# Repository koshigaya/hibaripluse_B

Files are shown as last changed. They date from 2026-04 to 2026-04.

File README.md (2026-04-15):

# hibaripluse_B
plethysmograph     

HibariPulse Basic is  a medical instrument, plethysmograph developed by Future Wave,Inc. in Tokyo, Japan.
We show source code, schematics, PCB layout and other information about HibariPulse Basic.

Hibari Pulse Basic is composed of sensor and PC apprication software. The sensor is connected to Windows PC by USB cable. PC apprication software is distributed in CD-R.

DD151207 is the folder of device driver for USB. Hibari Pulse Basic uses the device driver of FTDI,Inc. The user should install both PC apprication software and the device driver.

SK121105_delay10 is the folder of firmware.

pats_list111004.xls is BOM. The PCB has socket, but no MPU. MPU is ATMEGA328p-PU by Microchip Technology,Inc. 
So, first, we burn firmware on ROM in MPU. Second, we insert MPU on the socket.

apprication software :  Visual studio 2010(C#)  firmware :Arduino IDE  schematics:CADLUS Design by Nisoul, Inc.  PCB laout:CADLUS X by Nisoul. Inc.  CASE: JW-CAD(customized product byTAKACHI Co,.LTD)

***********************************
https://youtu.be/cTy66kJvDls?si=9v41cSytfnO6r9-v     another version (with OLED) https://youtu.be/LcAzEBJ3FTY?si=bp07WSiirY0aO0Qf

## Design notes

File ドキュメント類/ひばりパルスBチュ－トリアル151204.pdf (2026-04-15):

## ひばりパルス ベーシック

## 取扱説明書チュートリアル編

この取扱説明書はひばりパルス ベーシ
ックをはじめて使う方のための簡易版です。
詳しい情報は取扱説明書リファレンス編に
掲載されています。
取扱説明書リファレンス編は PDF デー
タで CD-R 内に入っています。または以下
の弊社サイトからダウンロードできます。

(http://www.bcchecker.com/docdown)

1.入っているもの
本体／CD-R／USB ケーブル／マウスパッ
ド／添付文書／取扱説明書チュートリアル
編(本書)

2.対応する PC について
本製品は Windows *PC と接続して使用
することを前提にしています。単独では作
動しませんのでご注意ください(Windows
は Microsoft 社の登録商標です)。
以下の PC で動作します。
①OS(いずれも 64 ビット版)：

Windows7, Windows8, Windows8.1,

Windows10
②CPU：Corei3 以上を推奨

3.注意事項
・ペースメーカーを装着している方は使用
しないでください。
・電源投入時(緑色 LED 点灯時)はセンサ部
から常時赤外線が発光していますので、
センサ部に眼を近づけないで下さい。

・電源投入時(緑色 LED 点灯時)は怪我や炎
症のある体の部位をセンサ部に接触させ
ないで下さい。
・測定中、センサ部に当てた指先に強い痛
みを感じたり、火傷したりしたときは、
ただちに測定を中止し、必要に応じて医
師の診断を受けて下さい。
・測定結果の自己診断、治療は危険ですの
で医師の指導に従って下さい。
・故障した場合は自分で修理、分解せず、
弊社までご連絡下さい。
・本製品に水をかけると故障する場合があ
ります。

4.インストール方法
最初にデバイスドライバをインストール
し、次にアプリケーションソフトをインス
トールします。デバイスドライバは CD-R
内のフォルダ「DD151207」の中に入って
います。
① PC の光学ドライバに付属の CD-R を挿
入します。
② 本製品本体と PC を USB ケーブルで接
続します。
③ デバイスドライバをインストールしま
す。インストールが完了すると正常にイ
ンストールされた旨のメッセージが出
力されます。
④ 通常、自動的にデバイスドライバのイン
ストールが始まりますので、画面の指示
に従ってください。途中、ディスクを挿

入する旨のメッセージが出力されたら、
①の通り挿入したことを確認して「次へ」
をクリックしてください。
うまく作動しない場合は手動のインス
トールに切り替えてください(詳細は取
扱説明書リファレンス編を参照)。
⑤ お使いの PC や環境によっては、手動で
インストールしなくてはならない場合
があります。その場合、デバイスドライ
バの参照先に CD-R 内のフォルダ
「DD151207」を指定します(詳細は取
扱説明書リファレンス編を参照)。
⑥ デバイスドライバのインストールが終
了したら、次にアプリケーションソフト
をインストールします。

⑦ まず CD-R 内の「Setup151202」をダ ブルクリックし、画面の指示に従います。
⑧ アイコンがデスクトップに表示された
ら、インストール作業はすべて完了です。

5.アプリケーションソフトの操作法
① ひばりパルス ベーシック本体と PC
を USB ケーブルで接続します。
② デスクトップ上のアイコンをダブルク
リックし、アプリケーションソフトを立
ち上げます。
③ 画面の空欄に被測定者の年齢を入力し
た後、「測定画面」をクリックし、「測定
画面」を立ち上げます。
④ 血管年齢を表示する場合はメニューバ
ーの機能(F)＞血管年齢の表示／非表示
(V)をクリックします。
⑤ 被測定者の指先を本体センサ部に載せ
ます。
⑥ 「測定」ボタンをクリックし、測定を開
始します。

⑦ 測定中、被測定者は体を動かさず、静か
にしています。
⑧ 測定が終了するとメッセージが出力さ
れます。測定結果の見方は図 1 を参照
してください。
⑨ 結果を印字する場合は「印刷」ボタンを
クリックしてください。
データを保存する場合はメニューバー
のファイル(F)＞データ書き込み(W)を
クリックしてください。保存したデータ
を見るときは、「測定画面」を閉じ、最
初の画面から「ビューワ」をクリックし
ます。「ビューワ」画面が立ち上がり、
保存データを見ることができます。
⑩ 22 波形分類で測定するときは機能(F)
＞22 波形分類／7 波形分類(Ｗ)をクリ
ックします。
後は 7 波形分類と操作法は同じです。
測定結果の見方は図 2 を参照してくだ
さい。

6.3 波形表示の操作法
最初の画面から「3 波形表示」をクリッ
クすると、「3 波形表示」画面が立ち上がり
ます。「3 波形表示」画面では加速度脈波の
他、容積脈波や速度脈波をモニタ表示でき
ます。

7.貯蔵方法
次のようなところに保管して下さい。
① 水等の液体のかからない場所
② 直射日光が当たらない場所
③ 高温(40℃以上)でない場所
④ 高湿(95％)でない場所

9.加速度脈波について
本製品は加速度脈波を測定する装置です。加速度脈波は末梢血液循環の状態を評価する もので、本製品では 7 波形分類の場合、良好な順に A～G までの 7 波形に分類されます。 被測定者の年齢によって、標準となる加速度脈波の波形が変わります。たとえば C 波形 は 25 歳ですと要注意ですが、40 歳では標準、72 歳では良好になります。標準よりも左側 の波形になれば良好、右側の波形になれば要注意です。
また 22 波形分類も同様に年齢に応じて三段階の評価をします。 加速度脈波は食生活や運動習慣など日頃の生活習慣の影響を受けます。

図 1 測定結果の見方(7 波形分類)

図 2 測定の見方(22 波形分類)

(T151204)

A | B | C | D | E | F | G
30 歳未満 | 良好 | 標準 | 要注意
30～59 歳 | 良 好 | 標準 | 要注 意
60 歳以上 | 良好 | 標 準 | 要注 意
A | B | C | B- | C- | E | D | E- | F | G
A+ | A | A- | B+ | B+X | B | BX | C+ | C | B- | B-X | C- | E+ | E | D+ | D | D- | E- | F/F- | G/G-
20～29 | 良好 | 標準 | 要注意
30～39 | 良好 | 標準 | 要注意
40～49 | 良好 | 標準 | 要注意
50～59 | 良好 | 標準 | 要注意
60～69 | 良好 | 標準 | 要注意
70 以上 | | 良好 | 要注意

## 品質保証書

製品名 | ひばりパルス ベーシック
保証期間 | お買い上げ日より 1 年間
販売店 | 会社名 住所 TEL お買い上げ日
お客様 | お名前 住所 TEL
1. 本製品が故障した場合、保証期間中でしたら弊社が無料で修理または良品交換いたしま す。その際、現品に本保証書を添えて弊社または弊社指定の修理業者へ郵送してくださ い。その際、送料はお客様負担でお願いいたします。なお本保証書がなくても製造番号 がわかれば無償修理できる場合があります。
2. 以下のような場合は、保証期間中でも有償修理となる場合があります。
① 不当な修理や改造による故障や損傷
② 著しく不適切な使用や保管による故障や損傷
③ お買い上げ後、お客様または第三者の故意による故障や損傷 ④ お買い上げ後、落下および輸送による故障や損傷

株式会社フューチャー・ウエイブ

〒176-0013 東京都練馬区豊玉中 3-2-17

TEL 03(5946)5922 FAX 03(5946)5923

URL http://www.bcchecker.com

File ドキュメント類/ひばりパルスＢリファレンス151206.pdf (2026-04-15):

# ひばりパルス ベーシック

# 取扱説明書リファレンス編

(R151206)

## 株式会社フューチャー・ウエイブ

# Fu ure

### 1.はじめに

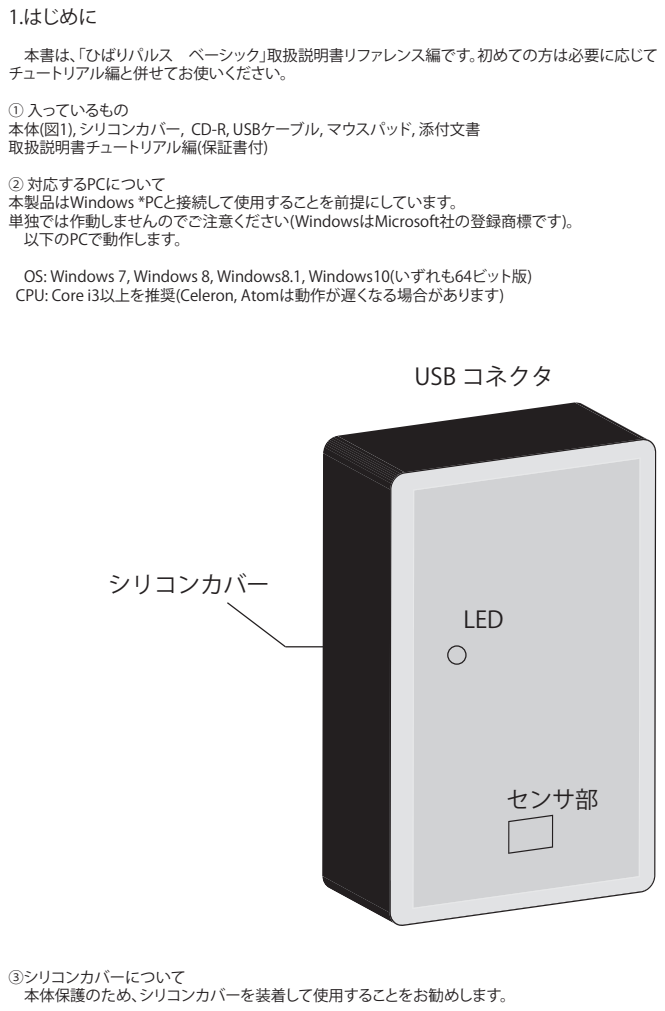
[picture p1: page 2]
③シリコンカバーについて 本体保護のため、シリコンカバーを装着して使用することをお勧めします。; センサ部; LED; シリコンカバー; USB コネクタ

本書は、「ひばりパルス　ベーシック」取扱説明書リファレンス編です。初めての方は必要に応じて
チュートリアル編と併せてお使いください。
① 入っているもの
本体(図1), シリコンカバー, CD-R, USBケーブル, マウスパッド, 添付文書
取扱説明書チュートリアル編(保証書付)
② 対応するPCについて
本製品はWindows *PCと接続して使用することを前提にしています。
単独では作動しませんのでご注意ください(WindowsはMicrosoft社の登録商標です)。
以下のPCで動作します。
OS: Windows 7, Windows 8, Windows8.1, Windows10(いずれも64ビット版)
CPU: Core i3以上を推奨(Celeron, Atomは動作が遅くなる場合があります)

寸法 | 81(W)×32(H)×141(D)
重量 | 200ｇ
電気的定格 | 5V(PC からの USB 電源 )

### ２. 本体定量仕様

### 3. 修理および技術サポートについて

修理および技術的サポートは弊社で受け付けます。できるだけ弊社サイトからメールでお問合 わせください。
修理の場合はメモ書きで故障内容を書いていただき、弊社まで郵送してください。納期希望など ございましたらメモ書きに併せてお書きください。保証期間中は、保証書(コピー可)を同封してくだ さい。修理が有償の場合、修理代金は修理品がこちらに到着してから故障状況を確認の上、お見積 りいたします。

### 株式会社フューチャー・ウエイブ

〒176-0013　東京都練馬区豊玉中3-2-17
TEL 03-5946-5922 FAX 03-5946-5923 URL http://www.hibaridenshi.com

【営業時間】
月～金　9：00～12：00　13：00～17：00 （土日、祭日は営業しておりません）

### 4.インストール方法

4-1.通常のインストール
最初にデバイスドライバをインストールし、次にアプリケーションソフトをインストールします。デバイス ドライバはCD-R内のフォルダ「DD151207」に入っています。
① PCの光学ドライバに付属のCD-Rを挿入します。
② 本製品本体とPCをUSBケーブルで接続します。
③ デバイスドライバをインストールします。インストールが完了すると正常にインストールされた旨のメッ セージが出力されます。
④ お使いのPCによって状況が異なる場合がありますが、通常は自動的にデバイスドライバのインストール が始まりますので、画面の指示に従ってください。途中、ディスクを挿入する旨のメッセージが出力された ら、①の通り挿入したことを確認して「次へ」をクリックしてください。 うまく作動しない場合は手動のインストールに切り替えてください。
⑤ 手動でインストールする場合は、デバイスドライバの参照先にCD-R内のフォルダ「DD151207」を指定し ます。詳細は「8.手動のインストール」または「ひばり電子商店」のサイトを参照してください。
⑥ デバイスドライバのインストールが終了したら、次にアプリケーションソフトをインストールします。CD-R 内の「Setup151201」をダブルクリックして、画面の指示に従ってください。 ⑦アイコンがデスクトップに表示されたら、インストール作業はすべて完了です。 4-2.COM番号の確認
インストールが完了したら、アプリケーションを起動できます。ただし、アプリケーションが正常に起動しな い場合に備え、デバイスドライバが正常にインストールされたことを確認するとともに、COM番号を記録して おくことをおすすめします。
①スタートボタンから「コントロールパネル＞ハードウェアとサウンド＞デバイスマネージャ」または 「コンピュータ＞システムのプロパティ＞デバイスマネージャでデバイスマネージャ」を立ち上げます。 ②デバイスマネージャで「ポート(COMとLPT)」内の「USB Serial Port(COM番号)」を探し、右クリックしてから プロパティをクリックします。「プロパティ>全般>デバイスの状態」で「デバイスは正常に動作しています」と いうメッセージが出力されたら、インストールは成功しています。
③念のため「USB Serial Port(COM番号)」のCOM番号(数字)を記録しておきます。COM番号は個々のPCによ って違います。
④②でデバイスが正常に動作していない旨のメッセージが出力されたら、「USB Seral Port(COM番号)」 を右クリックしてから「ドライバ－ソフトウェアの更新」をクリックし、画面の指示に従ってインストールをやり 直します。

## デバイスマネージャ

ポート (COM と LPT)

USB Serial Port(COM1)

## ひばりパルス

## 年齢を入力してください

歳

測定画面 | ３波形表示
ビューワ | 終了

### 5.アプリケーションソフトの操作方法

5-1．アプリケーションの起動と通常測定
① 本製品本体とPCをUSBケーブルで接続します。
② 本体の緑色LED窓から緑色の光が見えていることを確認します。本体に正しく電源が投入されれば、 緑色の光が見えます。
③ デスクトップ上のアイコンまたは、実行ファイル「hibari151201.exe」をダブルクリックし、アプリケー ションソフトを立ち上げます。実行ファイルは通常は以下の場所にあります。 C￥Program Files(x86)￥Future Wave￥Setup151202￥hibari151201.exe
④ 図のようなスタート画面が表示されます。空欄の下に「測定画面」、「3波形表示」、「ビューワ」、「終了」 のボタンがあります。
⑤ 画面の空欄に被測定者の年齢を入力した後、「測定画面」をクリックし、測定画面を立ち上げます。 年齢を入力しなくても測定できますが、この場合、年齢に対する評価や血管年齢は表示されません。 ⑥ 血管年齢を表示する場合はメニューバーの「機能(F)＞血管年齢の表示／非表示(V)」をクリックします。 画面左下に赤字で「血管年齢表示」の文字が表示されます。 血管年齢の表示をやめるときは同様に「機能(F)＞血管年齢の表示／非表示(V)」をクリックします。画面 左下の赤字で表示された「血管年齢表示」の文字が消えます。 ただしスタート画面で年齢を入力しなかった場合、血管年齢は表示されません。 ⑦被測定者の指先を本体センサ部に載せます。このとき被測定者は椅子に座り、本体が置いてある机の 上に肘をつき、力を抜いて軽くセンサ部に指先を触れているのが、正しく測定するために理想的な姿勢 です。
⑧ 「測定」ボタンまたは「機能(F)＞測定(M)」をクリックし、測定を開始します。 ⑨アプリケーションソフトと正しく接続できない場合は、 「4-2.COM番号の確認③」で控えたCOM番号を画 面の右上空欄に入力し、「測定」ボタンまたは「機能(F)＞測定(M)」をクリックします。 COM番号が1～20のときは該当番号をリスト(▼)から選ぶことができます。21以上のときは直接、半角 英数字で「COM**」(**は番号)を入力してください。
⑩ 測定中、被測定者はリラックスしています。体を動かさず、しゃべらず、静かにしています。なかなか測定 できないときは目をつぶります。
⑪メッセージボックスが表示されたら「OK」をクリックします。測定結果が表示され、測定終了です。

## ひばりパルス

測定

印刷

▼

閉じる

ファイル (F)　　機能 (K)

1A 2A 3A 4A 5A | APG
1B 2B 3B 4B 5B | pulse
1C 2C 3C 4C 5C | TW
1D 2D 3D 4D 5D
1W 2W 3W 4W 5W

⑫もう一度測定する場合は、「測定」ボタンまたは「機能(F)＞測定(M)」をクリックします。 ⑬結果を印字したり、データを保存したりすることもできます(5-2を参照)。 ⑭「閉じる」ボタンをクリックするか「ファイル(F)＞閉じる(C)」をクリックすると、スタート画面に戻り ます。ウインドウの“閉じるボタン（×)”をクリックしても同じです。
⑮ スタート画面の「終了」ボタンをクリックすると、アプリケーションは終了します。ウインドウの“閉 じるボタン（×)”をクリックしても同じです。
5-2.測定後の印刷およびデータ保存
①測定画面から、「印刷」ボタンまたは「ファイル(F)＞印刷(P)」をクリックすると、測定画面全体が印 刷されます。
②測定データを保存する場合は「ファイル(F)＞データ書き込み(W)」をクリックします。後は画面に 従い、BMP形式で測定画面全体のデータを保存します。

## 60 歳以上

30~59 歳

30 歳未満 | 良好 | 標準 | 要注意

良好

良好

標準

標準

要注意

要注意

A | B | C | D | E | F | G

5-3.測定結果の見方
本製品が測定する加速度脈波は末梢血液循環の状態を評価するものです。加速度脈波の波形は、本 製品では良好な順にA～Gまでの7波形に分類されます。 被測定者の年齢によって、標準となる加速度脈波の波形が変わります(上図)。たとえばC波形は25歳 ですと要注意ですが、40歳では標準、72歳では良好になります。標準よりも左側の波形になれば良好、 右側の波形になれば要注意です。
加速度脈波は食生活や運動習慣など日頃の生活習慣の影響を受けます。 5-4.容積脈波など3波形表示
①スタート画面から「3波形表示」ボタンをクリックします。 ②3波形表示画面が表示されます。
③被測定者の指先(通常、左右いずれかの人差し指又は中指)を本体センサ部に載せます。 ④「測定」ボタンをクリックし、測定を開始します。
⑤アプリケーションソフトと正しく接続できない場合は、 「4-2.COM番号の確認②」で控えたCOM番号を 画面の左上空欄に入力し「接続」ボタンをクリックします。COM番号が1～20のときは該当番号をリス ト(▼)から選ぶことができます。21以上のときは直接、半角英数字で「COM**」(**は番号)を入力してく ださい。
⑥上から容積脈波、速度脈波、加速度脈波がリアルタイム表示されます。 ⑦「切断」ボタンをクリックすると、3波形のリアルタイム表示が停止します（「切断」ボタンをクリックす るまで停止しません）。
⑧もう一度3波形をリアルタイム表示させるときは、③~④の操作を繰り返します。 ⑨「閉じる」ボタンをクリックすると、メイン画面に戻ります。ウインドウの“閉じるボタン（×)”をクリックし ても同じです。
5-5.上記3波形表示の保存
3波形表示の測定データを保存する場合は「保存」ボタンをクリックします。後は画面に従い、BMP形 式で測定画面全体のデータを表示します。
データを保存するときに、まず「中断」ボタンを押して動いていた3波形を停止させ、保存するデータを 確認してから「保存」ボタンをクリックする方法もあります。この方がイメージ通りのデータを保存しやす いですが、データ保存後は測定が停止しています。
もう一度測定する場合は、「測定」ボタンをクリックしてください。

## ひばりパルス

▼ | 閉じる

## ひばりパルス

データを開く | 印刷 | 閉じる

5-6.ビューワ
ビューワ画面での操作は本体をPCに接続しなくても動作します。 ①スタート画面から「ビューワ」ボタンをクリックします。 ②ビューワ画面(下図)が表示されます。
③「データを開く」ボタンをクリックします。後は画面に従い、表示したいBMPファイルを選択 すると図のように表示されます。
④画面上のデータを印刷する場合は「印刷」をクリックします。 ⑤別のデータを表示したいときは③~④の操作を繰り返します。 ⑥「閉じる」ボタンをクリックすると、メイン画面に戻ります。ウインドウの“閉じるボタン（×)”を クリックしても同じです。
測定 | 保存

20-29

30-39

40-49

50-59

60-69

70 以上

A+ A A- B+ B+X B BX C+ | C | B- B-X C- E+ E D+ D D- E- F/F- G/G-
：良好 | ：標準 | ：要注意

5-7.”新機能”22波形分類
本製品はデフォルトで７波形分類で測定結果を評価しますが、より詳細な22波形分類で評価すること ができます。この機能はバージョンアップ版から追加された新機能です。 メニューバーから「機能(F)＞22波形分類／7波形分類(W)」をクリックすると、画面左下に「22波形分 類」が表示されます。ところで、もう一度クリックすると表示が消えます。何も表示されていないときは7波 形分類、表示されているときは22波形分類で測定します。 測定方法は7波形分類の場合と同様です。画面左下に「22波形分類」が表示されている状態で、センサ 部に被測定者の指を載せ、「測定」ボタンまたは「機能(K)＞測定(M)」をクリックします。 保存や印字、血管年齢測定の有無も操作方法は、7波形分類と同様です。 測定中は波形分類を変更できません。波形分類の変更は、測定終了後に行います。 5-8.測定結果の見方(22波形分類)
上図が22波形分類での測定結果の見方です。7波形分類のときと同様、被測定者の年齢によって測定 結果が同じ波形でも評価が異なります。
22波形分類にすると7波形分類にくらべ、測定時間がやや長くなり、データ再現性もやや悪くなること が想定されますが、その分、より詳細な判定ができるのがメリットです。 状況に応じて、7波形分類測定と22波形分類測定を使い分けてください。 5-9.メッセージボックスの注意事項
測定後、メッセージボックスのＯＫボタンを複数回押さないと、メッセージボックスが消えない場合が あります。
またメッセージボックスに表示された加速度脈波係数がＯＫボタンを押すごとに変化し、測定画面に 表示される値(APG)と異なることがありますが、測定画面に表示される方が正しい値です。 センサ部からの入力情報が極端に複雑な場合や、PCのCPUの性能が低い場合に起きる現象です。 これは7波形分類で測定するときにも起きることがあります。

a

c

d
b

### 6.加速度脈波について

6-1.脈波計の原理
本製品は加速度脈波を測定する装置です。
光電脈波計ではまず被測定者の指先に赤外線を照射します。すると指先の血液中のヘモグロビンがそ の一部を吸収した後、残った反射光を受光素子などが電気的信号として捉えます。ところで指先の末梢血管 血流は循環しているため、反射光量は時間とともに変化しており、グラフ化すると波形が得られます。この波 形が指尖容積脈波です。
指尖容積脈波を時間軸で1回微分したものを速度脈波、2回微分したものを加速度脈波と呼びます。 日本の医学界を中心に加速度脈波に関する研究実績は多数あり、年齢と加速度脈波の相関関係、病気と 加速脈波の相関関係など、様々な臨床データが測定されています。加速度脈波を測定することで血圧や体 脂肪のように生活習慣病予防の指標に使えないかというのが、これらの研究の趣旨の一つです。 加速度脈波の評価方法は大きく分類して波形分類と加速度脈波係数に分かれます。波形分類は「5-3.測 定結果の見方」で説明したので、ここでは加速度脈波係数について説明します。 6-2.加速度脈波のa,b,c,dについて
加速度脈波を拡大すると図のようになります。変曲点に名前がついており、最初の山をa、次の谷をb、次 の山をc、次の谷をdと呼びます。グラフにしたとき、それぞれのY座標から、加速度脈波系数Yは以下のよう に算出されます。
Y = ((－ｂ+ｃ+ｄ)／a)×100
加速度脈波係数は加速度脈波を定量評価するための数値です。この値が高い方ほど末梢血管の血流状 態が良好ということになります。本製品では加速度脈波係数をスコアと呼んでいます。通常、加速度脈波係 数は+120～－120の範囲とされていますが、機械処理上の事情で本製品のスコアは+120以上の値をとる こともあります。
なお、本製品では内部的に以下のように計算しています。
Y＝((－ｂ／a)　+　c／a　+　d／a)×100
6-3.測定結果の数値の見方について
本製品は1回の測定間に内部的には5回以上測定し、その平均を最終的な測定結果としています。つまり 1～5回分の加速度脈波係数を測定し、その平均を最終的なスコアとしているのです。波形分類の場合は5 回測定中、同一波形が3回以上観測されたら、それを最終的な波形と判定します。ただし、1～5回分の各波 形が一定以上のばらつきがある場合は測定自体を無効と判断し、もう一度測定を繰り返します。

## ひばりパルス

測定

接続

▼

閉じる

ファイル (F)　　機能 (K)

1A 2A 3A 4A 5A | APG
1B 2B 3B 4B 5B | pulse
1C 2C 3C 4C 5C | TW
1D 2D 3D 4D 5D
1W 2W 3W 4W 5W

測定画面を上図に示します。
それぞれ左から列ごとに1回目（1A~1W)、2回目(2A~2W)、3回目(3A~3W)、4回目(4A~4W)、5回 目(5A~5W)の測定結果です。また上から行ごとに
| (1A~5A)が加速度脈波係数、
| (1B~5B)が(－ｂ／a)×100　、
| (1C~5C)が(c／a)×100　、
| (1D~5D)が(d／a)×100、
| (1W~5W)が波形です。

左端の数字は上からそれぞれ5回分の平均の加速度脈波係数(APG)、脈拍(pulse)、代表波形 (TW)です。
脈拍は測定精度を評価するために表示しています。本製品開発の基盤になった学術的研究で は、脈拍が100以下の臨床データのみ有効ですので、脈拍が100を超える場合の測定結果はあまり 正しくありません。正確に測定したい場合は、測定終了後、まず脈拍が100を超えていないことを確 認し、もし超えていたら再測定してださい。
ところで、加速度脈波係数と「5-3.測定結果の見方」で説明した7波形分類は、まったく違ったア プローチから測定しています。一般に両者の測定結果は近いと考えられますが、片方が良好な結 果なのにもう片方が悪い結果になっていることもあります。 本製品の場合、加速度脈波係数のデータ再現性が波形分類に比べ、想定的に低いと考えらえま すので、このような場合は波形分類の評価を優先していただくよう、おすすめしています。 ただし、もう一度測定して、加速度脈波係数と波形分類がともに同等な結果になることが最も理 想的です。

### 7.安全上の注意事項

7-1.禁忌・禁止
①電源投入時(緑色LED点灯時)はセンサ部から常時赤外線が発光していますので、センサ部に眼を近づけ ないで下さい。
②電源投入時(緑色LED点灯時)は怪我や炎症のある体の部位をセンサ部に接触させないで下さい。 ③測定中、センサ部に当てた指先に強い痛みを感じたり、火傷したりしたときは、ただちに測定を中止し、必 要に応じて医師の診断を受けて下さい。
④測定結果の自己診断、治療は危険ですので医師の指導に従って下さい。 ⑤ペースメーカーを装着している方は使用しないで下さい。
7-2.使用上の注意
①本製品はPCと接続して使用することを前提としています。単独では作動しません。 ②脈拍の測定に使用しないで下さい。脈拍は100を超えていないかどうかを確認するために表示されます。 100を超えている場合、加速度脈波の測定精度は低いと考えられ、再測定が必要になります。 ③騒音のない静かな場所で測定して下さい。
④測定時はできるだけ体を動かさないで下さい。
⑤USBケーブルにはフェライトコアを使用して下さい。
7-3.貯蔵・保管方法
次のようなところに保管して下さい。
①水等の液体のかからない場所
②直射日光が当たらない場所
③高温(40℃以上)でない場所
④高湿(95％)でない場所
7-4.保守・点検に係る事項
①故障した場合は自分で修理、分解せず、弊社までご連絡下さい。 ②許可なく改造しないで下さい。
③センサ部や緑色LED窓から筐体内部にゴミが入らないよう注意して下さい。 ④本体の汚れは乾いたやわらかい布で拭き取って下さい。 ⑤汚れがひどいときは、水または中性洗剤をしみ込ませた布をよく絞ってから、汚れを拭き取った後、乾い た布でから拭きして下さい。
⑥本製品に水または化学薬品をかけると故障の原因になる場合があります。

### 8.手動のインストール

以下のサイトを参照してください。なお、デバイスドライバはフォルダ「DD151207」内にあります。以下の 説明では旧バージョンのフォルダ名になっていますので、ご注意ください。

①Windows7の場合 http://hibaridenshi.blogspot.jp/2013/07/windows7.html
②Windows8の場合 http://hibaridenshi.blogspot.jp/2013/03/windows8.html

### 9.診療報酬について

本製品は以下のように分類される医療機器です。

製造販売届出番号　13B3X00116000102
脈波計（70060000）　一般医療機器　特定保守管理医療機器　クラスⅠ

この他、JIS T0601-1の電気安全試験では本製品は、「B型　クラスⅡ機器」にほぼ準拠していることを確認 しました。ただし、これは第三者認証機関によるものでなく、自社責任による試験です。 また本製品を診断に使用した場合、以下の診療報酬の取得が推定されます。ただし、診療報酬は各支払 基金団体がレセプトを査定して決定するものであり、弊社が以下の点数を保証するものではありません。

区分：　D214　脈波図検査（脈波図、心機図、ポリグラフ検査）
点数：　1検査/60点　2検査/80点　3又は4検査/130点　5又は6検査/180点　7検査以上/220点

運動や薬剤の負荷による検査を行った場合、負荷前後の検査を1回の検査として算定してください。 なお、脈波図検査は、以下の2種類の波形を記録する必要があります。

ア　心及び肝拍動図
イ　動脈波
ウ　静脈波
エ　容積脈波
オ　指尖脈波
カ　心尖(窩)拍動図

3波形表示画面で測定結果を保存または印刷すると、容積脈波、速度脈波、加速度脈波を記録したことに なります。加速度脈波を指尖脈波とみなせば、エ(容積脈波)とオ(指尖脈波)が記録されます。

# 株式会社フューチャー・ウエイブ

## 〒176-0013 東京都練馬区豊玉生 3-2-17 TEL: 03(5946)5922 FAX: 03(5946)5923 URL: http://www.hibaridenshi.com

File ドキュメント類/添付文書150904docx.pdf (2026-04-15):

1/2

作成年月日 2015 年 9 月 4 日 | 許可番号 13B3X00116000102

器具機械 18 血圧検査又は脈波検査用具

脈波計 70060000 一般医療機器 特定保守管理医療機器

# ひばりパルス ベーシック

【形状・構造及び原理】

1. 構成
本体：図 1 参照
付属品：①CD-R、②USB ケーブル、
③マウスパッド、④書類(取扱説明書等)
2.寸法及び重量

寸法：81(W)×32(H)×141(D)mm
重量：200ｇ
3.電気的定格

DC5.0V(PC からの USB バスパワー)

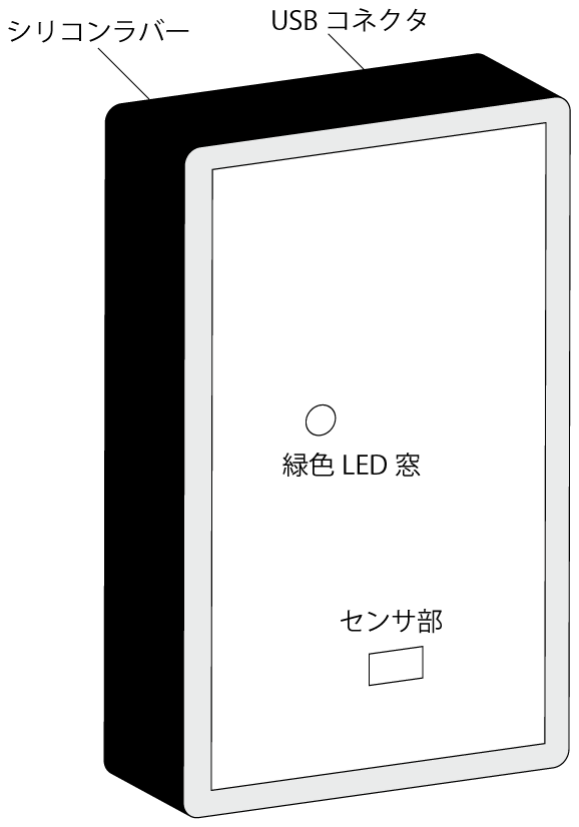
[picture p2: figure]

図 1

4.作動・動作原理

(1)本製品は Windows PC と接続し、PC か らの電源で作動します。
(2)本体のセンサ部に当てた指先に赤外線を
照射し、指先の血液中のヘモグロビンが
その一部を吸収した後、残った反射光を
フォトインタラプタが電気的信号として
捉えます。
(3)指先の末梢血管血流は循環しているため、
反射光量は時間とともに変化しており、
グラフ化すると光電脈波が得られます。

【禁忌・禁止】
1. 電源投入時(緑色 LED 点灯時)はセン
サ部から常時赤外線が発光していま
すので、センサ部に眼を近づけないで
下さい。
2. 電源投入時(緑色 LED 点灯時)は怪我
や炎症のある体の部位をセンサ部に
接触させないで下さい。
3. 測定中、センサ部に当てた指先に強い
痛みを感じたり、火傷したりしたとき
は、ただちに測定を中止し、必要に応
じて医師の診断を受けて下さい。
4. 測定結果の自己診断、治療は危険です
ので医師の指導に従って下さい。
5. ペースメーカーを装着している方は
使用しないで下さい。

取扱説明書を必ず参照下さい

2/2

(4)光電脈波の情報を PC に送信し、専用
アプリケーションソフトがそれを解析
して加速度脈波の波形を算出した後、臨
床データに基づき、評価・判定します。

【使用目的、効能又は効果】
健康管理のため、又は末梢血液循環の状
態を診断するため、加速度脈波の状態を臨
床データに基づいて評価します。

【品目仕様等】
自社試験により、本製品が JIS T0601-1
にほぼ準拠していることを確認しました。
(B 形 クラスⅡ機器)

【操作方法又は使用方法等】
(1) 本体を USB 経由で PC と接続し、専
用アプリケーションソフトを立ち上
げます。
(2) PC 上の画面に被測定者の年齢を入
力し、「測定画面へ」ボタンをクリッ
クします。
(3) 本体のセンサ部に被測定者の指先(通
常、左右いずれかの人差し指又は中
指)を当て、「測定」ボタンをクリック
し、測定を開始します。
(4) 測定が終了すると、PC 上の画面に測
定結果が表示されます。必要に応じて
測定結果を印字又は保存して下さい。

【使用上の注意】
(1) 脈拍の測定に使用しないで下さい。
(2) 騒音のない静かな場所で測定して下
さい。
(3) 測定時はできるだけ体を動かさない
で下さい。
(4) USB ケーブルにはファライトコアを
巻いて下さい。

【貯蔵・保管方法及び使用期間等】
1. 貯蔵方法
次のようなところに保管して下さい。
① 水等の液体のかからない場所
② 直射日光が当たらない場所
③ 高温(40℃以上)でない場所
④ 高湿(95％)でない場所
2. 耐用期間
製造日から 5 年間

【保守・点検に係る事項】
(1) 故障した場合は自分で修理、分解せず、
弊社までご連絡下さい。
(2) 許可なく改造しないで下さい。
(3) 本体の汚れは乾いたやわらかい布で
拭き取って下さい。
(4) 本製品に水又は化学薬品をかけると
故障の原因になる場合があります。

【包装】
1 式／1 梱包

【製造販売業者及び製造業者の名称及び
住所等】
株式会社フューチャー・ウエイブ

〒176-0013 東京都練馬区豊玉中 3-2-17

Tel: 03-5946-5922 Fax: 03-5946-5923

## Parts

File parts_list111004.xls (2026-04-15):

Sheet: 入力方法と記入例
データ登録時の注意事項
設計サービスは、実装する電子部品型番よりデータシートを検索し記載された部品外形サイズより、基板設計ＣＡＤで配置・配線に使用する
部品（フットプリント）を作成します。
電子部品型番が特定できないと、部品（フットプリント）が特定できず、設計作業を進めることができなくなります。
また、電子部品型番が誤っていると、部品実装時に部品同士が干渉し実装できない場合がございます。
実装サービスは、無料提供部品を除く実装部品をお客様よりご提供いただき、ご登録いただく「部品リスト」をもとに部品入荷検品を行います。
ご登録いただいた資料を「正」として作業を進めますので、間違いがないかご登録時に再度資料のご確認をお願いします。
入力方法
 | No. |  |  | 連番
 | 設計/実装 サービス共通 | メーカー名 |  | 電子部品のメーカー名を入力してください。
 |  | 電子部品型番 （必須・半角英数字） |  | ※面実装部品のコンデンサ(電解、タンタル以外)や抵抗は、外形寸法に従い、後述「設計サービス指示図２」の部品名称を入力していただければ「メーカー名」は不要です。
 |  | 個数 （必須・半角英数字） |  | 「電子部品型番」の種類毎の実装個数を入力してください。 未実装は「未実装」と入力してください。
 | 設計サービスのみ | 回路記号 （必須・半角英数字） |  | ※複数の回路記号を入力する場合は、カンマ「,」区切りで入力してください。
 |  | ピン数 （必須・半角英数字） |  | 端子の総ピン数を入力してください。※基板取付穴、部品取付穴、全てのスルー・ノンスルーホール、面実装部品のパッド、及び次の①～⑤の配線を伴う箇所（①テストピン、②チェックランド、③引き出しランド、④ジャンパピン、⑤入出力ランドの総計。
 | 実装サービスのみ | 配置番号 （必須・半角英数字） |  | シルク図/配置図に表記された記号/番号を入力してください。
 |  | パッケージ 情報 | 部品外形 | 「0-MR4/NM」「0.1u/p」など
 |  |  | 部品仕様 | 「1608」「1005」など
 |  | お客様 支給 部品 | SMD品 | 表面実装部品
 |  |  | BGA/CSP/LGA /QFN/HQFP | BGA/CSP、LGA/QFN部品が含まれている場合に☑してください。 ＢＧＡ：Ball Grid Array 下面に半田ボールの端子を配置したパッケージ。 ＣＳＰ：Ｃｈｉｐ Ｓｉｚｅ Ｐａｃｋａｇｅ／Ｃｈｉｐ Ｓｃａｌｅ Ｐａｃｋａｇｅ チップサイズと同じか、もしくはわずかに 大きいパッケージ。 LGA：Land Grid Array 裏面に外部入出力用のランドを設けたパッケージ。BGAの半田ボールが ない状態。 QFN：QFPに似ていますが、外部入出力用のピンが出ていないパッケージ。
 |  | 無料提供部品 |  | 無料提供部品が含まれている場合に☑してください。 無料提供部品：チップコンデンサ/チップ抵抗を約1500種、実装サービスをご利用のお客様に無料提供いたします。
 |  |  |  | http://www.p-ban.com/implementation/chip.html
 |  | P板.com調達部品 |  | 調達希望部品が含まれている場合に☑してください。 P板.com調達部品は、無料提供部品以外に弊社での調達を希望される部品のことです。 ※調達費用のお見積もりは、部品リストの返却と同時にご連絡いたします。 ※納期によっては調達できない部品もございますので、予めご了承ください。
 |  |  | 調達不可 | P板.com調達部品で調達が不可となった部品は、見積回答時に弊社で☑いたします。 ※お客様の方で、ご記入する必要はございません。
 |  | 代替部品 |  | 無料提供部品の在庫切れや、P板.com調達部品で調達不可となった部品に対して、弊社より代替部品としてご提案させていただきます。
記入例
設計サービス指示図１
コネクターの場合 |  |  |  |  |  | トランスの場合
設計サービス指示図２
１．チップ部品（抵抗、コンデンサ）
 |  |  |  |  | 単位：ｍｍ
 | 部品タイプ | Ａ寸法 | Ｂ寸法 | 抵抗 電子部品型番 | コンデンサ 電子部品型番
 | １６０８タイプ | 1.6 | 0.8 | R1608 | C1608
 | ２１２５タイプ | 2 | 1.25 | R2125 | C2125
 | ３２１６タイプ | 3.2 | 1.6 | R3216 | C3216
 | ３２２５タイプ | 3.2 | 2.5 | R3225 | C3225
 | ４５３２タイプ | 4.5 | 3.2 | R4532 | C4532
２．チップタンタルコンデンサ
 |  |  |  | 単位：ｍｍ
 | 部品タイプ | Ａ寸法 | Ｂ寸法 | 電子部品型番
 | ３２１６タイプ | 3.2 | 1.6 | CT3216
 | ３５２８タイプ | 3.5 | 2.8 | CT3528
 | ４７２６タイプ | 4.7 | 2.6 | CT4726
 | ６０３２タイプ | 6 | 3.2 | CT6032
 | ５８４６タイプ | 5.8 | 4.6 | CT5846
 | ７３４３タイプ | 7.3 | 4.3 | CT7343
３．チップアルミ電解コンデンサ
 |  |  |  |  |  | 単位：ｍｍ
 | 外形サイズ |  | Ａ寸法 | Ｂ寸法 | C寸法 | 電子部品型番
 | ３．３×３．３ |  | 3.3 | 3.3 | φ３．０ | CE33
 | ４．３×４．３ |  | 4.3 | 4.3 | φ４．０ | CE43
 | ５．３×５．３ |  | 5.3 | 5.3 | φ５．０ | CE53
 | ６．６×６．６ |  | 6.6 | 6.6 | φ６．３ | CE66
 | ８．３×８．３ |  | 8.3 | 8.3 | φ８．０ | CE83
 | １０．３×１０．３ |  | 10.3 | 10.3 | φ１０.０ | CE103

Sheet: 部品リスト入力フォーム
No. | 共通 |  |  |  | 設計サービスのみ |  |  | 実装サービスのみ
 | メーカー名 | 部品名称 | 電 子 部 品 型 番 （半角英数字） | 個数 | 回 路 記 号 （半角英数字） | ピ ン 数 (部品取付穴 を含む） |  | 配 置 番 号 （半角英数字） 回路記号と同じなら不要 | 実装 個数 | 実装枚数を入力してください。↓ | パッケージ情報 (部品外形/部品仕様) | お客様支給部品 |  | 無料 提供 部品 | P板.com 調達 部品 (有料） |  | 代替部品 |  | 入荷数 | 返却
 |  |  |  |  |  |  |  |  |  |  |  | SMD品 | BGA /CSP /LGA /QFN /HQFP |  |  | 調達 不可
 |  |  |  |  |  | 1個 あたり | 合計 |  |  |  |  |  |  |  |  |  | メーカー名 | 型名
 |  |  |  | 44 |  | 50 | 50 |  | 0 | 0 |  |  |  | リスト (http://www.p-ban.com/implementation/chip.html)
1 | KOA | 抵抗 | RK73H2ATTD3300F | 2 | R |  | 0 | R1,R8 |  | 2 | 2012
2 | KOA | 抵抗 | RK73B1ETTP104J | 1 | R |  | 0 | R2 |  | 2 | 1005
3 | KOA | 抵抗 | RK73B1ETTP223J | 1 | R |  | 0 | R3 |  | 2 | 1005
4 | KOA | 抵抗 | RK73B1ETTP103J | 3 | R |  | 0 | R4,R6,R7 |  | 2 | 1005
5 | KOA | 抵抗 | RK73B1ETTP105J | 1 | R |  | 0 | R5 |  | 2 | 1005
6 | KOA | 抵抗 | RK73B2ATTD240J | 4 | R |  | 0 | R9,R10,R11,R12 |  | 2 | 2012
7 | 村田製作所 | コンデンサ | GRM188B31E105K75J | 4 | C |  | 0 | C1,C2,C4,C5 |  | 2 | 1608
8 | 村田製作所 | コンデンサ | GRM188B31H104K | 12 | C |  | 0 | C3,C6,C10,C11,C12,C13,C14,C15,C17,C19,C20, C22 |  | 2 | 1608
9 | 村田製作所 | コンデンサ | GRM1552C1H220J | 2 | C |  | 0 | C7,C8 |  | 2 | 1005
10 | 村田製作所 | コンデンサ | GRM31CF11E106KA75L | 5 | C |  | 0 | C9,C16,C18,C21,C23 |  | 2 | 3216
11 | Para Light | LED | L-513GT3 | 1 | D | 2 | 2 | D1 |  | 0 | DIP
12 | Mercury | 水晶発振子 | HUS（16MHz 3.5ｍｍ） | 1 | X | 2 | 2 | X1 |  | 0 | HC-49/U-S
13 | ローム | フォトインタラプタ | PRP-220 | 1 | U | 4 | 4 | U1 |  | 0 | DIP
14 | National Semiconductor | オペアンプ | LMC6482AIN | 1 | U | 8 | 8 | U2 |  | 0 | DIP
15 | FTDI | MPR | FT232RL | 1 | U |  | 0 | U3 |  | 0 | SOP
16 | Analog Devices | デジタルアイソレータ | ADuM4160 | 1 | U |  | 0 | U4 |  | 0 | SOP
17 | Analog Devices | デジタルアイソレータ | ADuM6000 | 1 | U |  | 0 | U5 |  | 0 | SOP
18 | Neltron | ICソケット | 2227-28-03 | 1 | CN | 28 | 28 | CN1 |  | 0 | DIP
19 | ？ | USBコネクタ | #USB_B? | 1 | CN | 6 | 6 | CN2 |  | 0 | USBメスB端子
20 |  |  |  |  |  |  | 0 |  |  | 0
21 |  |  |  |  |  |  | 0 |  |  | 0
22 |  |  |  |  |  |  | 0 |  |  | 0
23 |  |  |  |  |  |  | 0 |  |  | 0
24 |  |  |  |  |  |  | 0 |  |  | 0
25 |  |  |  |  |  |  | 0 |  |  | 0
26 |  |  |  |  |  |  | 0 |  |  | 0
27 |  |  |  |  |  |  | 0 |  |  | 0
28 |  |  |  |  |  |  | 0 |  |  | 0
29 |  |  |  |  |  |  | 0 |  |  | 0
30 |  |  |  |  |  |  | 0 |  |  | 0
31 |  |  |  |  |  |  | 0 |  |  | 0
32 |  |  |  |  |  |  | 0 |  |  | 0
33 |  |  |  |  |  |  | 0 |  |  | 0
34 |  |  |  |  |  |  | 0 |  |  | 0
35 |  |  |  |  |  |  | 0 |  |  | 0
36 |  |  |  |  |  |  | 0 |  |  | 0
37 |  |  |  |  |  |  | 0 |  |  | 0
38 |  |  |  |  |  |  | 0 |  |  | 0
39 |  |  |  |  |  |  | 0 |  |  | 0
40 |  |  |  |  |  |  | 0 |  |  | 0
41 |  |  |  |  |  |  | 0 |  |  | 0
42 |  |  |  |  |  |  | 0 |  |  | 0
43 |  |  |  |  |  |  | 0 |  |  | 0
44 |  |  |  |  |  |  | 0 |  |  | 0
45 |  |  |  |  |  |  | 0 |  |  | 0
46 |  |  |  |  |  |  | 0 |  |  | 0
47 |  |  |  |  |  |  | 0 |  |  | 0
48 |  |  |  |  |  |  | 0 |  |  | 0
49 |  |  |  |  |  |  | 0 |  |  | 0
50 |  |  |  |  |  |  | 0 |  |  | 0
51 |  |  |  |  |  |  | 0 |  |  | 0
52 |  |  |  |  |  |  | 0 |  |  | 0
53 |  |  |  |  |  |  | 0 |  |  | 0
54 |  |  |  |  |  |  | 0 |  |  | 0
55 |  |  |  |  |  |  | 0 |  |  | 0
56 |  |  |  |  |  |  | 0 |  |  | 0
57 |  |  |  |  |  |  | 0 |  |  | 0
58 |  |  |  |  |  |  | 0 |  |  | 0
59 |  |  |  |  |  |  | 0 |  |  | 0
60 |  |  |  |  |  |  | 0 |  |  | 0
61 |  |  |  |  |  |  | 0 |  |  | 0
62 |  |  |  |  |  |  | 0 |  |  | 0
63 |  |  |  |  |  |  | 0 |  |  | 0
64 |  |  |  |  |  |  | 0 |  |  | 0
65 |  |  |  |  |  |  | 0 |  |  | 0
66 |  |  |  |  |  |  | 0 |  |  | 0
67 |  |  |  |  |  |  | 0 |  |  | 0
68 |  |  |  |  |  |  | 0 |  |  | 0
69 |  |  |  |  |  |  | 0 |  |  | 0
70 |  |  |  |  |  |  | 0 |  |  | 0
71 |  |  |  |  |  |  | 0 |  |  | 0
72 |  |  |  |  |  |  | 0 |  |  | 0
73 |  |  |  |  |  |  | 0 |  |  | 0
74 |  |  |  |  |  |  | 0 |  |  | 0
75 |  |  |  |  |  |  | 0 |  |  | 0
76 |  |  |  |  |  |  | 0 |  |  | 0
77 |  |  |  |  |  |  | 0 |  |  | 0
78 |  |  |  |  |  |  | 0 |  |  | 0
79 |  |  |  |  |  |  | 0 |  |  | 0
80 |  |  |  |  |  |  | 0 |  |  | 0
81 |  |  |  |  |  |  | 0 |  |  | 0
82 |  |  |  |  |  |  | 0 |  |  | 0
83 |  |  |  |  |  |  | 0 |  |  | 0
84 |  |  |  |  |  |  | 0 |  |  | 0
85 |  |  |  |  |  |  | 0 |  |  | 0
86 |  |  |  |  |  |  | 0 |  |  | 0
87 |  |  |  |  |  |  | 0 |  |  | 0
88 |  |  |  |  |  |  | 0 |  |  | 0
89 |  |  |  |  |  |  | 0 |  |  | 0
90 |  |  |  |  |  |  | 0 |  |  | 0
91 |  |  |  |  |  |  | 0 |  |  | 0
92 |  |  |  |  |  |  | 0 |  |  | 0
93 |  |  |  |  |  |  | 0 |  |  | 0
94 |  |  |  |  |  |  | 0 |  |  | 0
95 |  |  |  |  |  |  | 0 |  |  | 0
96 |  |  |  |  |  |  | 0 |  |  | 0
97 |  |  |  |  |  |  | 0 |  |  | 0
98 |  |  |  |  |  |  | 0 |  |  | 0
99 |  |  |  |  |  |  | 0 |  |  | 0
100 |  |  |  |  |  |  | 0 |  |  | 0
101 |  |  |  |  |  |  | 0 |  |  | 0
102 |  |  |  |  |  |  | 0 |  |  | 0
103 |  |  |  |  |  |  | 0 |  |  | 0
104 |  |  |  |  |  |  | 0 |  |  | 0
105 |  |  |  |  |  |  | 0 |  |  | 0
106 |  |  |  |  |  |  | 0 |  |  | 0
107 |  |  |  |  |  |  | 0 |  |  | 0
108 |  |  |  |  |  |  | 0 |  |  | 0
109 |  |  |  |  |  |  | 0 |  |  | 0
110 |  |  |  |  |  |  | 0 |  |  | 0
111 |  |  |  |  |  |  | 0 |  |  | 0
112 |  |  |  |  |  |  | 0 |  |  | 0
113 |  |  |  |  |  |  | 0 |  |  | 0
114 |  |  |  |  |  |  | 0 |  |  | 0
115 |  |  |  |  |  |  | 0 |  |  | 0
116 |  |  |  |  |  |  | 0 |  |  | 0
117 |  |  |  |  |  |  | 0 |  |  | 0
118 |  |  |  |  |  |  | 0 |  |  | 0
119 |  |  |  |  |  |  | 0 |  |  | 0
120 |  |  |  |  |  |  | 0 |  |  | 0
121 |  |  |  |  |  |  | 0 |  |  | 0
122 |  |  |  |  |  |  | 0 |  |  | 0
123 |  |  |  |  |  |  | 0 |  |  | 0
124 |  |  |  |  |  |  | 0 |  |  | 0
125 |  |  |  |  |  |  | 0 |  |  | 0
126 |  |  |  |  |  |  | 0 |  |  | 0
127 |  |  |  |  |  |  | 0 |  |  | 0
128 |  |  |  |  |  |  | 0 |  |  | 0
129 |  |  |  |  |  |  | 0 |  |  | 0
130 |  |  |  |  |  |  | 0 |  |  | 0
131 |  |  |  |  |  |  | 0 |  |  | 0
132 |  |  |  |  |  |  | 0 |  |  | 0
133 |  |  |  |  |  |  | 0 |  |  | 0
134 |  |  |  |  |  |  | 0 |  |  | 0
135 |  |  |  |  |  |  | 0 |  |  | 0
136 |  |  |  |  |  |  | 0 |  |  | 0
137 |  |  |  |  |  |  | 0 |  |  | 0
138 |  |  |  |  |  |  | 0 |  |  | 0
139 |  |  |  |  |  |  | 0 |  |  | 0
140 |  |  |  |  |  |  | 0 |  |  | 0
141 |  |  |  |  |  |  | 0 |  |  | 0
142 |  |  |  |  |  |  | 0 |  |  | 0
143 |  |  |  |  |  |  | 0 |  |  | 0
144 |  |  |  |  |  |  | 0 |  |  | 0
145 |  |  |  |  |  |  | 0 |  |  | 0
146 |  |  |  |  |  |  | 0 |  |  | 0
147 |  |  |  |  |  |  | 0 |  |  | 0
148 |  |  |  |  |  |  | 0 |  |  | 0
149 |  |  |  |  |  |  | 0 |  |  | 0
150 |  |  |  |  |  |  | 0 |  |  | 0
151 |  |  |  |  |  |  | 0 |  |  | 0
152 |  |  |  |  |  |  | 0 |  |  | 0
153 |  |  |  |  |  |  | 0 |  |  | 0
154 |  |  |  |  |  |  | 0 |  |  | 0
155 |  |  |  |  |  |  | 0 |  |  | 0
156 |  |  |  |  |  |  | 0 |  |  | 0
157 |  |  |  |  |  |  | 0 |  |  | 0
158 |  |  |  |  |  |  | 0 |  |  | 0
159 |  |  |  |  |  |  | 0 |  |  | 0
160 |  |  |  |  |  |  | 0 |  |  | 0
161 |  |  |  |  |  |  | 0 |  |  | 0
162 |  |  |  |  |  |  | 0 |  |  | 0
163 |  |  |  |  |  |  | 0 |  |  | 0
164 |  |  |  |  |  |  | 0 |  |  | 0
165 |  |  |  |  |  |  | 0 |  |  | 0
166 |  |  |  |  |  |  | 0 |  |  | 0
167 |  |  |  |  |  |  | 0 |  |  | 0
168 |  |  |  |  |  |  | 0 |  |  | 0
169 |  |  |  |  |  |  | 0 |  |  | 0
170 |  |  |  |  |  |  | 0 |  |  | 0
171 |  |  |  |  |  |  | 0 |  |  | 0
172 |  |  |  |  |  |  | 0 |  |  | 0
173 |  |  |  |  |  |  | 0 |  |  | 0
174 |  |  |  |  |  |  | 0 |  |  | 0
175 |  |  |  |  |  |  | 0 |  |  | 0
176 |  |  |  |  |  |  | 0 |  |  | 0
177 |  |  |  |  |  |  | 0 |  |  | 0
178 |  |  |  |  |  |  | 0 |  |  | 0
179 |  |  |  |  |  |  | 0 |  |  | 0
180 |  |  |  |  |  |  | 0 |  |  | 0
181 |  |  |  |  |  |  | 0 |  |  | 0
182 |  |  |  |  |  |  | 0 |  |  | 0
183 |  |  |  |  |  |  | 0 |  |  | 0
184 |  |  |  |  |  |  | 0 |  |  | 0
185 |  |  |  |  |  |  | 0 |  |  | 0
186 |  |  |  |  |  |  | 0 |  |  | 0
187 |  |  |  |  |  |  | 0 |  |  | 0
188 |  |  |  |  |  |  | 0 |  |  | 0
189 |  |  |  |  |  |  | 0 |  |  | 0
190 |  |  |  |  |  |  | 0 |  |  | 0
191 |  |  |  |  |  |  | 0 |  |  | 0
192 |  |  |  |  |  |  | 0 |  |  | 0
193 |  |  |  |  |  |  | 0 |  |  | 0
194 |  |  |  |  |  |  | 0 |  |  | 0
195 |  |  |  |  |  |  | 0 |  |  | 0
196 |  |  |  |  |  |  | 0 |  |  | 0
197 |  |  |  |  |  |  | 0 |  |  | 0
198 |  |  |  |  |  |  | 0 |  |  | 0
199 |  |  |  |  |  |  | 0 |  |  | 0
200 |  |  |  |  |  |  | 0 |  |  | 0
201 |  |  |  |  |  |  | 0 |  |  | 0
202 |  |  |  |  |  |  | 0 |  |  | 0
203 |  |  |  |  |  |  | 0 |  |  | 0

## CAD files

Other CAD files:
ハードウェア160315/KEN110926/KEN110926.PLY
筐体160315/hp111031.dxf
